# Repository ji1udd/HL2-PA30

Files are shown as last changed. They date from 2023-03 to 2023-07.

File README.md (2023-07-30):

# PA30 - 30W amplifier/filter companion board for Hermes Lite 2+ / 2

## All board, Hermes Lite 2 beta5, AK4951 companion board v3 and PA30 companion board v1, are installed in Makerfabs 40mm height enclosure.

### Exterior view
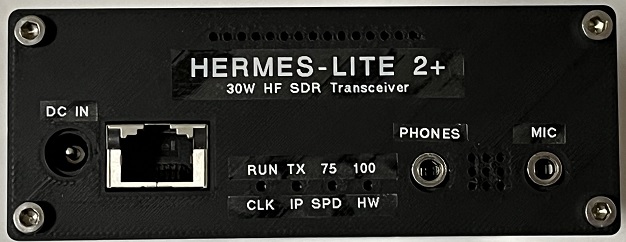
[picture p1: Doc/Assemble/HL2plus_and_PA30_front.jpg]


### Interior view (PA30 ver1 board)
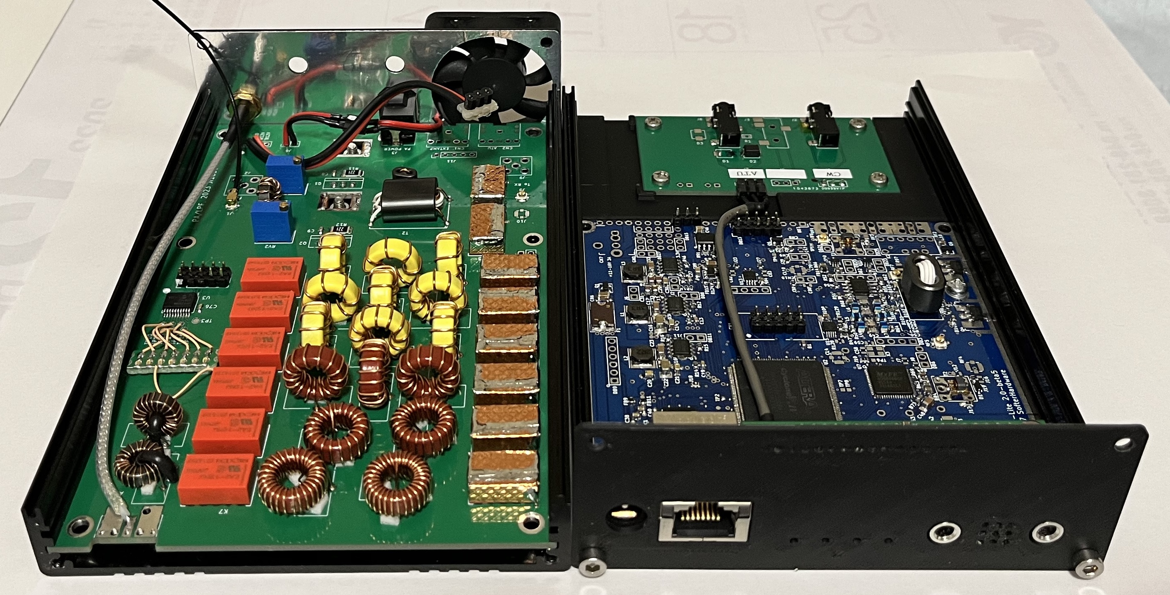
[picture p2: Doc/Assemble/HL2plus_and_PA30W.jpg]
  

### Feature
- RD15HVF1 push-pull 30W linear amplifier.
- A retired notebook AC adaptor is used to supply 19.5V to RD15HVF1.
- Tx/Rx LPF and Rx HPF ; same control as N2ADR filter
- FWD/REV sensor ; Alex type
- Tx RF feedback path for PureSignal.
- Phones and Mic Jacks are placed on the front panel, and CW key jack on the rear.

### Test result
- [_Tx Power with comparison of RD15HVF1s and RD16HHF1s_](Doc/PowerMeter/RD15_RD16_comparison_on_PA30.jpg)  
  Tx power is lower if RD16s is used instead of RD15s.
- [_Thetis FWD Power Meter_](Doc/PowerMeter/Test_FwdMeter_40M_CW.jpg)
- Spur at 30W [_160M_](Doc/Spur/Spur_160M_30W.jpg) , [_80M_](Doc/Spur/Spur_80M_30W.jpg) , [_40M_](Doc/Spur/Spur_40M_30W.jpg) , [_20M_](Doc/Spur/Spur_20M_30W.jpg) , [_15M_](Doc/Spur/Spur_15M_30W.jpg)
- PureSignal at 30W [_ON_](Doc/PureSignal/IMD_40M_30W_PS-ON.jpg), [_OFF_](Doc/PureSignal/IMD_40M_30W_PS-OFF.jpg)

### Latest design files ver2.1
There are some errata on my 1st design (v1). Schematic and pcb layout have been revised to fix them. There is no DRC error on KiCad but these are not actually build and verified.
- [_Schematic_](Schematic/PA30_v2r1_schematic.pdf)
- [_BOM_](BOM/PA30_BOM.pdf)
- [_Gerber_](Gerber/PA30_v2r1.zip)
- [_PA30-HL2 board connection_](Schematic/PA30_HL2_connection.pdf)

### PA30 Assembly
- Trans and coil  
    [_T1_](Doc/Assemble/T1_bifilar_12turns.jpg) , [_T2_](Doc/Assemble/T2_4turns_1turnx2.jpg) , [_L1_](Doc/Assemble/L1_1turn.jpg)  
    T3, T4 : UEW 0.32mm  
    LPF 160M, 80M : UEW 0.5mm  
    LPF 40M, 30/20M, 17/15M, 12/10M : UEW 0.6mm
- RD15HVF1 grounding  
    It's necessary to connect RD15HVF1 source tab to GND pattern of PCB  shortly. Otherwise amplifier will not work well. eg. lower power output... Copper tape is used. ( [_Photo_](Doc/Assemble/RD15Tab.jpg) )   
- RD15HVF1 idle current  
    Q1, Q2 idle current is set to 250mA per Tr (total 500mA).

### HL2 modification
- Reduce HL2 RF output power to avoid over drive ; 37dBm -> 26dBm  
    R55 : Replace 120ohms with 750ohms. Otherwise Q1 and Q2 will be broken.

- uFL Tx output  
    RF7 and B55 : Install  
    B98 : Uninstall

- uFL Rx input  
    RF5 : Install  
    B81 : Uninstall

- CW KEY jack  
    Jack(CN4) and jumper(J13) : Uninstall to get clearance to jacks on CBV3.  ( [_Photo_](Doc/Assemble/CN4_1.jpg) )   
    Instead of the uninstalled jack CN4, 3.5mm jack is placed on rear panel. ( [_Photo_](Doc/Assemble/CN4_2.jpg) )  
    Wire is used to connect between PCB and the jack.

- Pin Header  
    Low profile pin header and socket are used.   ( [_Photo_](Doc/Assemble/LowProfilePinHeader.jpg) )  
    CN1, DB1, DB12, DB13, DB7 Pin12-14 ( [_Photo_](Doc/Assemble/HL2_PinHeader.jpg) )

### AK4951 CBV3 modification  
- [_Stacked boards Photo_](Doc/Assemble/stacked_boards.jpg)
- Mic/PTT jack and Phone jack  
    They are relocated on the opposite PCB side. ( [_Photo_](Doc/Assemble/CBV3_1.jpg) )  
    Therefore the signals assigned to Tip and Ring are swapped.   
    C3 10uF on CBV3 is removed to mount Mic/PTT jack. There is no side effect in my case.

- Pin Header  
    Low profile pin header and socket are used.   ( [_Photo_](Doc/Assemble/LowProfilePinHeader.jpg) )  

- Jack Spacer (option)  
    The B2B Pin Header/Socket height and jack height are different.  
    Therefore 3D printed spacer (t = 0.7mm) is used between jack and PCB to fix tightly. ( [_Photo_](Doc/Assemble/CBV3_2.jpg) )  

- CVB3 Support part (option)  
    The 3D printed support part that fixes CBV3 and HL2 tightly, is used. ( [_Photo_](Doc/Assemble/CBV3_3.jpg) ) 

### Cooling fan
- 40mm square. ( [_Photo_](Doc/Assemble/fan.jpg) )

### Shield (option)  
- This is risk hedge.  I have not verified if it's essencial or not.
- Relay shield (copper tape is used) intend to isolate LPF input and output, and to isolate Tx  and Rx. ( [_Photo_](Doc/Assemble/relay_shield.jpg) )
- 3D printed shield between HL2 and PA30  
    Aluminum tape is used. ( [_Photo_](Doc/Assemble/B2B_shield.jpg) )

### 3D print files
- [_Jack spacer_](3D_Print/jack_3r5_spacer%20v3.stl)
- [_CBV3 support_](3D_Print/HL2_cbv3_support%20v1.stl)
- [_B2B Shield_](3D_Print/RF_shield%20v32.stl)
- [_Front Panel_](3D_Print/FrontPanel%20v1.stl)
- [_Rear Panel_](3D_Print/HL2_RearPanel2%20v4.stl)
- [_HL2 spacer instead of N2ADR board_](3D_Print/HL2_spacer3%20v5.stl)

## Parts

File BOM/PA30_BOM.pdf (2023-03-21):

Designator | Qty. | Value/Description | Package | Manufacture | Manufacturer P/N | Supplier | Supplier P/N
C1, C2 | 2 | CAP CER 1uF 25V X5R | 0603(1608) | Murata | GRM188R71E105KA12
C3, C6, C7, C11, C12, C15, C16, C19, C20, C21, C22, C23, C24, C25, C26, C27, C28, C29, C30, C69, C70, C71, C72, C73, C74, C75, C76, C77, C81, C82, C83, C84, C85, C86, C87, C88, C89, C90, C91, C92, | 40 | CAP CER 100nF 50V X7R | 0603(1608) | Samsung | CL10B104KB8NNNL | Digi-Key | 1276-CL10B104KB8NNNLCT-ND
C4, C5, C8, C9 | 4 | CAP CER 100nF 100V X7R 10% | 0603(1608) | Samsung | CL10B104KC8NNNC | Mouser | 187-CL10B104KC8NNNC
C10, C44, | 2 | CAP CER 270pF 630V C0G 5% | 1206(3216) | TDK | C3216C0G2J271J060AA | Mouser | 810-C3216C0G2J271J
C13, C14, C17, C18, | 4 | CAP CER 22uF 25V X5R | 0805(2012) | Murata | GRM21BR61E226ME44L | Mouser | 81-GRM21BR61E226ME4L
C31, C65, | 2 | CAP CER 330pF 630V C0G 5% | 1206(3216) | Yageo | CC1206JKNPOZBN331 | Mouser | 603-CC206JKNPOZBN331
C32, C46, C58, | 3 | CAP CER 120pF 630V C0G 5% | 1206(3216) | Walsin | 1206N121J631CT | Mouser | 791-1206N121J631CT
C33, C94, | 2 | CAP CER 47pF 500V C0G 5% | 1206(3216) | Walsin | 1206N470J501CT | Mouser | 791-1206N470J501CT
C34, C49, C63, | 3 | CAP CER 39pF 500V C0G 5% | 1206(3216) | Yageo | CC1206JRNPOBBN390 | Mouser | 603-CC126JRNPOBBN390
C35, | 1 | CAP CER 1500pF 630V C0G 5% | 1206(3216) | TDK | C3216C0G2J152J115AA | Mouser | 810-C3216C0G2J152J
C36, | 1 | CAP CER 560pF 630V C0G 5% | 1206(3216) | TDK | C3216C0G2J561J085AA | Mouser | 810-C3216C0G2J561J
C37, | 1 | DNI
C38, C68, | 2 | CAP CER 27pF 500V C0G 5% | 1206(3216) | Yageo | CC1206JRNPOBBN270 | Mouser | 603-CC126JRNPOBBN270
C39, | 1 | CAP CER 15pF 500V C0G 5% | 1206(3216) | Yageo | CC1206JRNPOBBN150 | Mouser | 603-CC126JRNPOBBN150
C40, | 1 | CAP CER 8.2pF 500V C0G ±0.5pF | 1206(3216) | Walsin | 1206N8R2D501CT | Mouser | 791-1206N8R2D501CT
C41, C57, | 2 | CAP CER 150pF 630V C0G 5% | 1206(3216) | Yageo | CC1206JKNPOZBN151 | Mouser | 603-CC126JKNPOZBN151
C42, C62, | 2 | CAP CER 82pF 500V C0G 5% | 1206(3216) | Murata | GRM31A5C2H820JW01D | Mouser | 81-GRM31A5C2H820JW1D
C43, C55, | 2 | CAP CER 680pF 500V C0G 5% | 1206(3216) | Yageo | CC1206JRNPOBBN681 | Mouser | 603-C1206JRNPOBBN681
C45, | 1 | CAP CER 160pF 630V C0G 1% | 1206(3216) | KEMET | C1206C161JBGACTU | Mouser | 80-C1206C161JBG
C47, | 1 | CAP CER 3000pF 500V C0G 5% | 1206(3216) | KEMET | C1206C302JCGACTU | Mouser | 80-C1206C302JCGACTU
C48, C59, | 2 | CAP CER 1200pF 630V C0G 5% | 1206(3216) | TDK | C3216C0G2J122J085AA | Mouser | 810-C3216C0G2J122J
C50, C61, | 2 | CAP CER 100pF 630V CH 5% | 1206(3216) | TDK | C3216CH2J101J060AA | Mouser | 810-C3216CH2J101J06A
C51, | 1 | CAP CER 43pF 630V C0G 5% | 1206(3216) | KEMET | C1206C430JBGACTU | Mouser | 80-C1206C430JBG
C52, C64, C95, | 3 | CAP CER 33pF 500V C0G 5% | 1206(3216) | Yageo | CC1206JRNPOBBN330 | Mouser | 603-CC126JRNPOBBN330
C53, | 1 | CAP CER 510pF 630V 5% | 1206(3216) | KEMET | C1206C511JBGACTU | Mouser | 80-C1206C511JBG
C54, C56, | 2 | CAP CER 220pF 630V 5% | 1206(3216) | TDK | C3216C0G2J221J060AA | Mouser | 810-C3216C0G2J221J
C60, | 1 | CAP CER 470pF 500V C0G 5% | 1206(3216) | Yageo | CC1206JRNPOBBN471 | Mouser | 603-CC206JRNPOBBN471
C66, | 1 | CAP CER 68pF 630V C0G 5% | 1206(3216) | Walsin | 1206N680J631CT | Mouser | 791-1206N680J631CT
C67, | 1 | CAP CER 22pF 500V C0G 5% | 1206(3216) | Yageo | CC1206JRNPOBBN220 | Mouser | 603-CC126JRNPOBBN220
C78, C80, | 2 | CAP CER 1500pF 100V C0G 5% | 0805(2012) | TDK | CGA4C2C0G2A152J060AA | Mouser | 810-CGA4C2C0G2A152J
C79, | 1 | CAP CER 680pF 100V C0G 5% | 0805(2012) | Yageo | CC0805JRNPO0BN681 | Mouser | 603-CC805JRNPO0BN681
C93, | 1 | CAP CER 10pF 500V C0G 5% | 1206(3216) | Yageo | CC1206JRNPOBBN100 | Mouser | 603-CC126JRNPOBBN100
CN1, CN2 | 1 | 3.5mm Jack 3-contact | - | CUI | SJ1-3525N | Mouser | 490-SJ1-3525N
D1, D2, D3, D4, | 4 | Schottky Diode | SOD-323 | Diodes Nexperia | 1N5711WS RB751V40,115 | Mouser | 771-RB751V40,115
D5, | 1 | Diode 1000V 1A | DO-214AC(SMA) | Diodes | S1M-13-F | Mouser | 621-S1M-F
D6, | 1 | TVS Diode | DO-214AC(SMA) | Littelfuse | SMBJ6.0CA | Mouser | 576-SMBJ6.0CA
D7, D8, D9, D10, D11, D12, D13, | 7 | LED | 0603(1608) | Lite-On | LTST-C190GKT | Mouser | 859-LTST-C190GKT
F1, | 1 | Resettable Fuse 3A | - | Bourns | MF-LSMF300/24X-2 | Mouser | 652-MF-LSMF300/24X-2
FB1, | 1 | FB 100MHz 1A.25% | 0603 (1608) | TDK | MPZ1608S601ATA00 | Mouser | 810-MPZ1608S601ATA00
J1, J8, J10, J13, | 4 | uFL Male | - | - | - | Aliexpress
J2, J9, | 2 | SMA | - | - | - | - | -
J3, | 1 | DC POWER JACK EIAJ-5 | - | CUI | PJ-025 | Mouser | 490-PJ-025

J4, | 1 | SMA/BNC | - | - | - | - | -
J5, | 1 | Low Profile Pin header 2.54mm 5 x 2 pin | - | - | - | - | -
J6, J12, | 1 | Low Profile Pin header 2.54mm 2 x 1 pin | - | - | - | - | -
J7, | 1 | Low Profile Pin header 2.54mm 3 x 1 pin | - | - | - | - | -
J11, | 1 | Pin header 2.54mm 5 x 1 pin | - | - | - | - | -
K1, K2, K3, K4, K5, K6, K7, K8, K9, K10, K11, K12, K13, K14, | 14 | EA2-12 | - | KEMET | EA2-12NU | DigiKey | 399-17332-5-ND
L1, | 1 | multi-aperture core | - | Amidon | BN43-2402 | Kits and Parts | BN43-2402
L2, L6, L7, L8, L12, L13, L14, | 7 | powdered iron toroid | - | Amidon | T50-2 | Kits and Parts | T50-2
L3, L4, L5, L9, L10, L11, L15, L16, L17, | 9 | powdered iron toroid | - | Amidon | T50-6 | Kits and Parts | T50-6
L18, L19, | 2 | IND 1.8uH | 0805(2012) | Taiyo Yuden | LBM2016T1R8J | Mouser Digi-Key | 963-LBM2016T1R8J 587-3092-1-ND
Q1, Q2, | 2 | RF Power MOS FET | TO-220 | Mitsubishi | RD15HVF1 | RS | 690-0127
Q3, | 1 | Pch FET | SOIC-8 | Diodes | 621-DMP3036SSS-13 | Mouser | 621-DMP3036SSS-13
Q4, | 1 | Pch FET | SOT23_3 | Infineon | IRLML6402TRPBF | Digi-Key | IRLML6402PBFCT-ND
Q5, | 1 | Nch FET | SOT-23 | ONsemi | 2N7002ET1G | Mouser | 863-2N7002ET1G
R1, | 1 | RES 560 ohm | 0603(1608)
R2, R6, | 2 | DNI | 0805(2012) | - | - | - | -
R3, | 1 | RES 0 ohm | 0805(2012)
R4, | 1 | RES 4.7k ohm | 0603(1608)
R5, | 1 | RES 2.2k ohm | 0603(1608)
R7, R8, R19, R21, R29, | 5 | RES 1k ohm | 0603(1608)
R9, R10, | 2 | RES 10 ohm | 0603(1608)
R11, R12, | 2 | RES 220 ohm 0.75W 1% | 2010(5025) | Yageo | RC2010JK-07220RL | Mouser | 603-RC2010JK-07220RL
R13, R30, | 2 | RES 56 ohm | 0603(1608)
R14, R16, | 2 | RES 100k ohm | 0603(1608)
R15, | 1 | RES 49.9 ohm 0.1W 1% | 0603(1608) | Bourns | CR0603-FX-49R9ELF | Mouser | 652-CR0603FX-49R9ELF
R17, R18, | 2 | RES 220k | 0603(1608)
R20, R22, | 2 | RES 1.8k | 0603(1608)
R23, | 1 | RES 100 ohm | 0603(1608)
R24, R28, | 2 | RES 10k ohm | 0603(1608)
R25, R27, | 2 | RES 110 ohm | 0603(1608)
R26, | 1 | RES 51.1 ohm | 0603(1608)
R31, | 1 | RES 430 ohm | 0603(1608)
R32, R33, R34, R35, R36, R37, R38, | 7 | RES 1.5k ohm | 0603(1608)
RV1, RV2, | 2 | RES Trimmer 10k ohm | - | Bourns | 3296W-1-103LF | Mouser | 652-3296W-1-103LF
T1, T3, T4, | 3 | ferrite toroid | - | Amidon | FT37-43 | Kits and Parts | FT37-43
T2, | 1 | multi-aperture core | - | Amidon | BN43-202 | Kits and Parts | BN43-202
U1, | 1 | Shunt Regulator | SOT89-3 | Toshiba | TA76431F | Chip One Stop | C1S751200341120
U2, | 1 | OPAMP | SOIC-8 | TI | LMC6482IMX/NOPB | Digi-Key | LMC6482IMXCT-ND
U3, | 1 | I/O Expander | SSOP-20 | Microchip | MCP23008-E/SS | Digi-Key | MCP23008T-E/SS
U4, | 1 | Low Side Driver | TSSOP-16 | Diodes TI TI | ULN2003V12T16-13 TPL7407LPWR TPL7407LAPWR | Mouser | 621-ULN2003V12T16-13 595-TPL7407LPWR 595-TPL7407LAPWR
HL2 RF7 - PA30 J1 | 1 | uFL/IPEX-1 cable Female-Female 10cm | Aliexpress
HL2 RF5 - PA30 J8 PA30 J10 - PA30 J13 | 2 | uFL/IPEX-1 cable Female-Female 15cm | Aliexpress

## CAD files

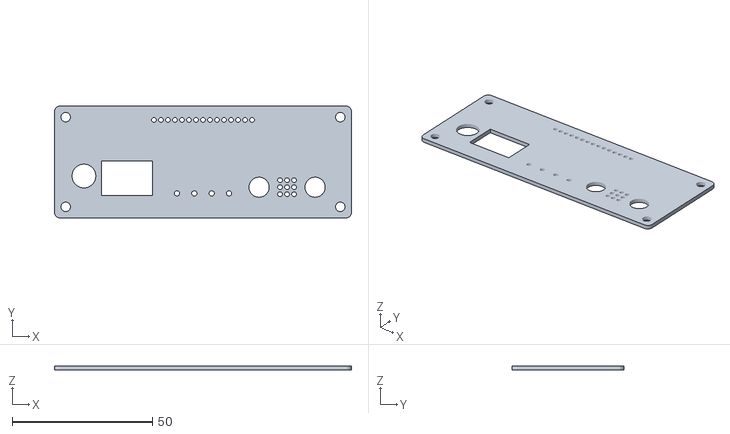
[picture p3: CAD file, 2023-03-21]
3D_Print/FrontPanel v1.stl
106.0 x 40.0 x 1.50

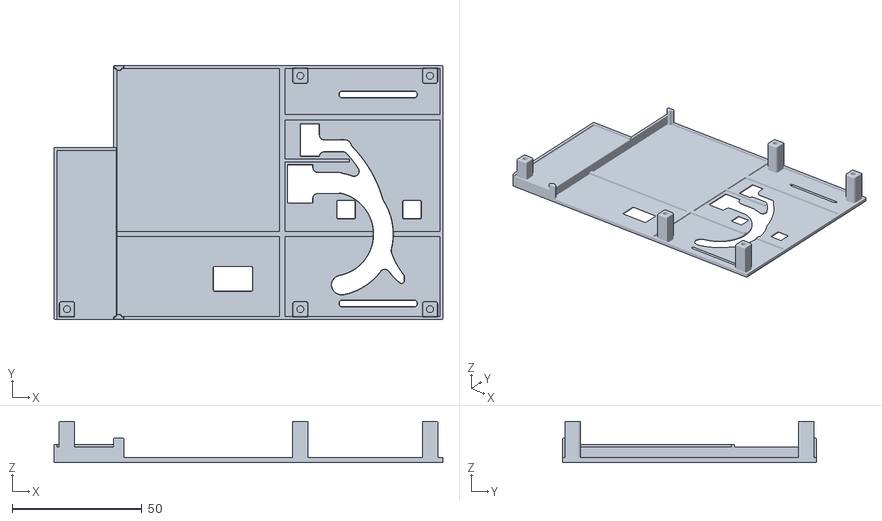
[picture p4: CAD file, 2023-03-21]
3D_Print/RF_shield v32.stl
150.0 x 98.0 x 16.0

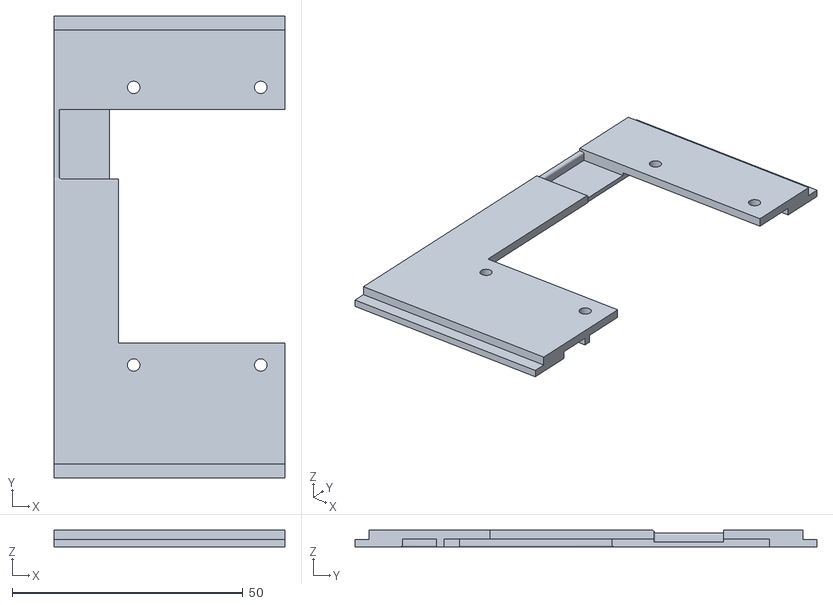
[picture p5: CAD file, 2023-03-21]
3D_Print/HL2_spacer3 v5.stl
50.0 x 100.0 x 3.60

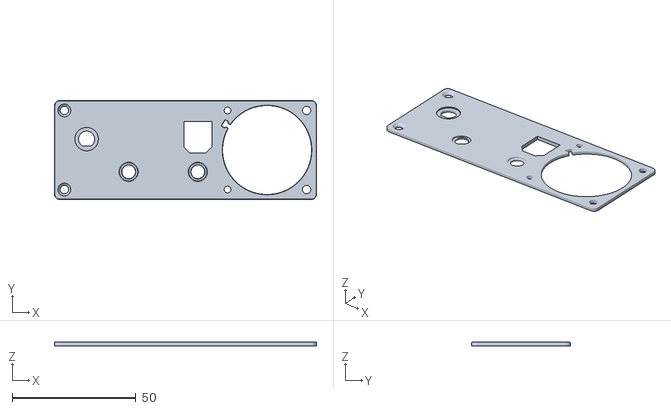
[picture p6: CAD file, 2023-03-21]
3D_Print/HL2_RearPanel2 v4.stl
106.0 x 40.0 x 1.50

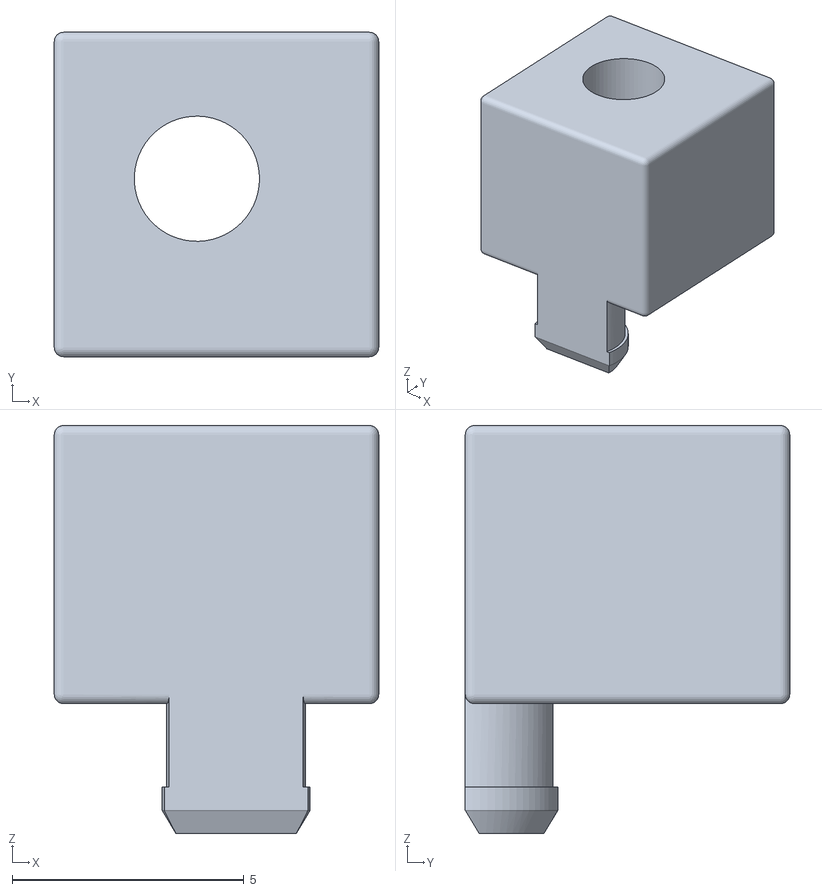
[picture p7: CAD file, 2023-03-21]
3D_Print/HL2_cbv3_support v1.stl
7.00 x 7.00 x 8.80

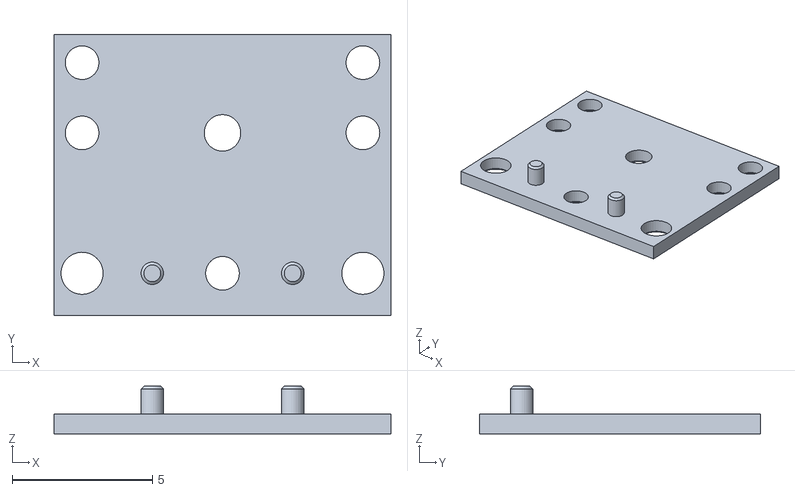
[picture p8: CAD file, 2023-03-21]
3D_Print/jack_3r5_spacer v3.stl
12.0 x 10.0 x 1.70

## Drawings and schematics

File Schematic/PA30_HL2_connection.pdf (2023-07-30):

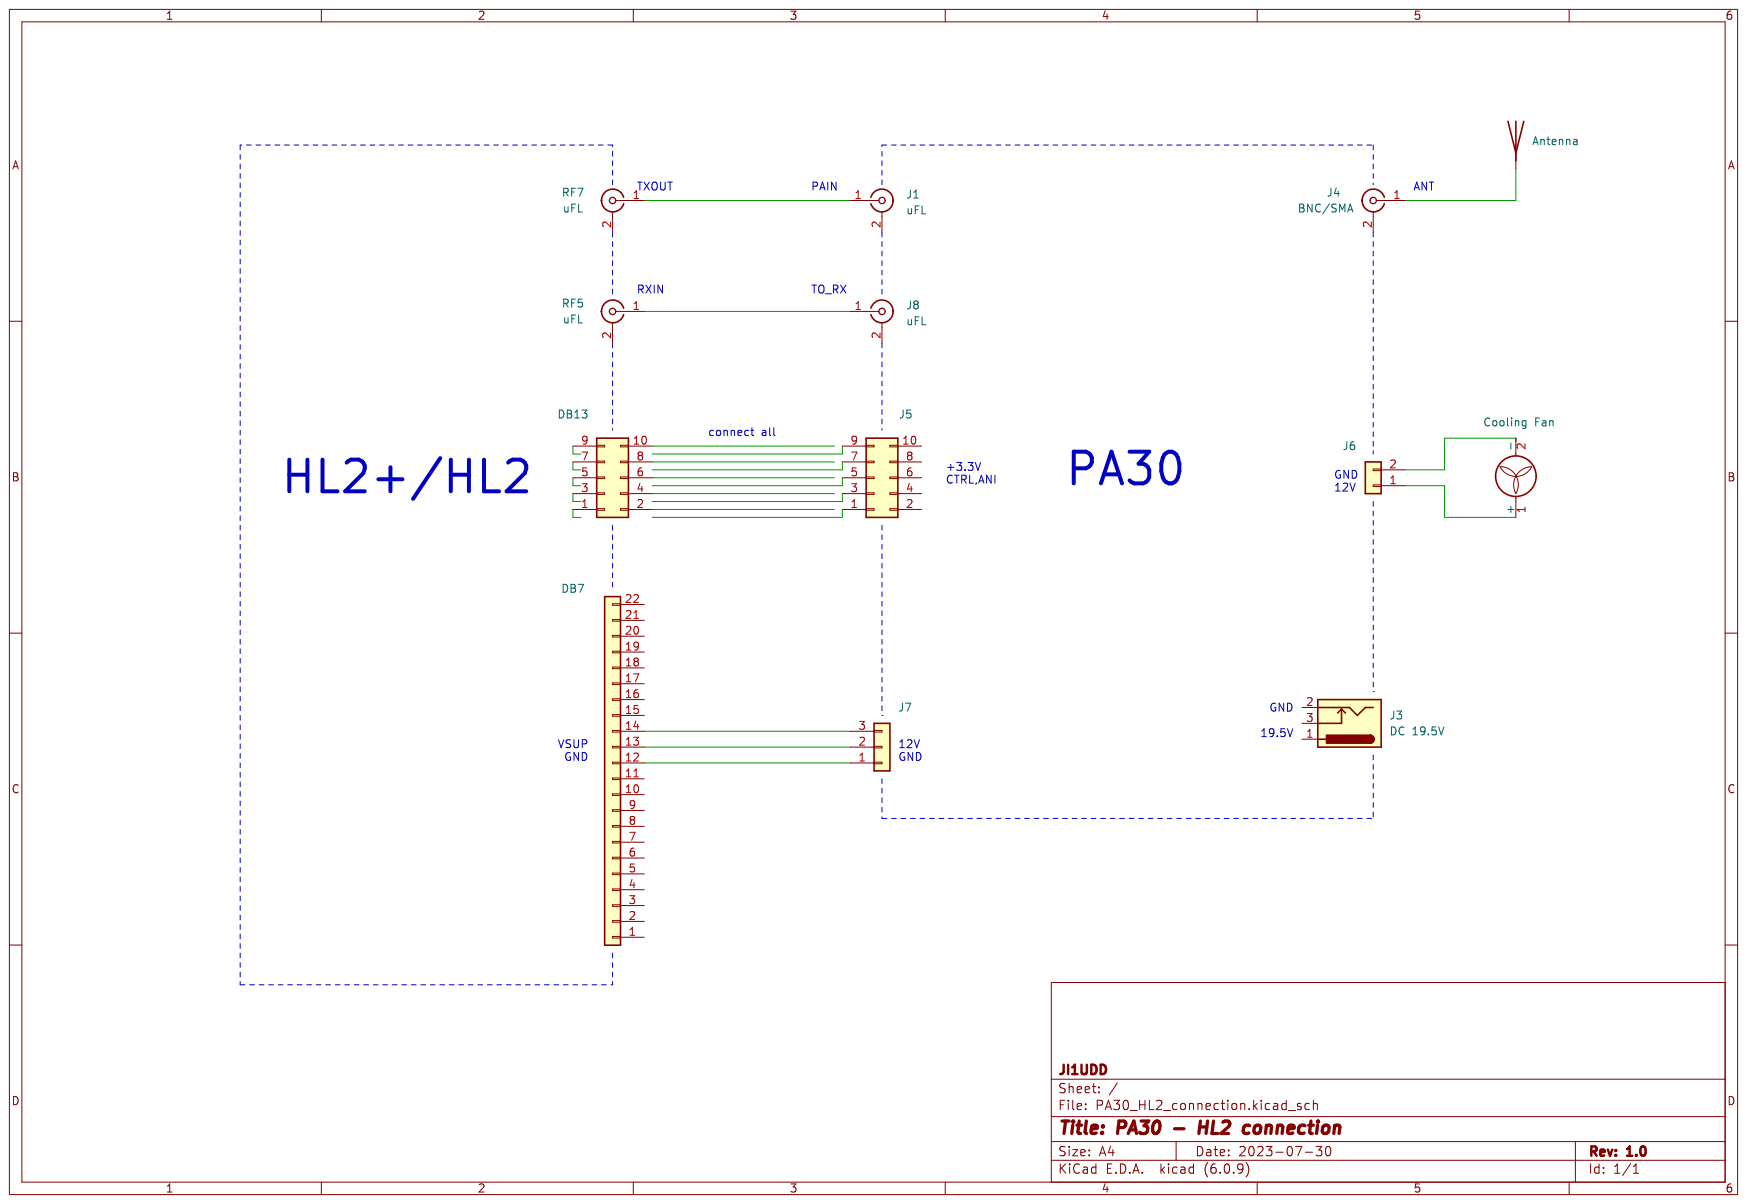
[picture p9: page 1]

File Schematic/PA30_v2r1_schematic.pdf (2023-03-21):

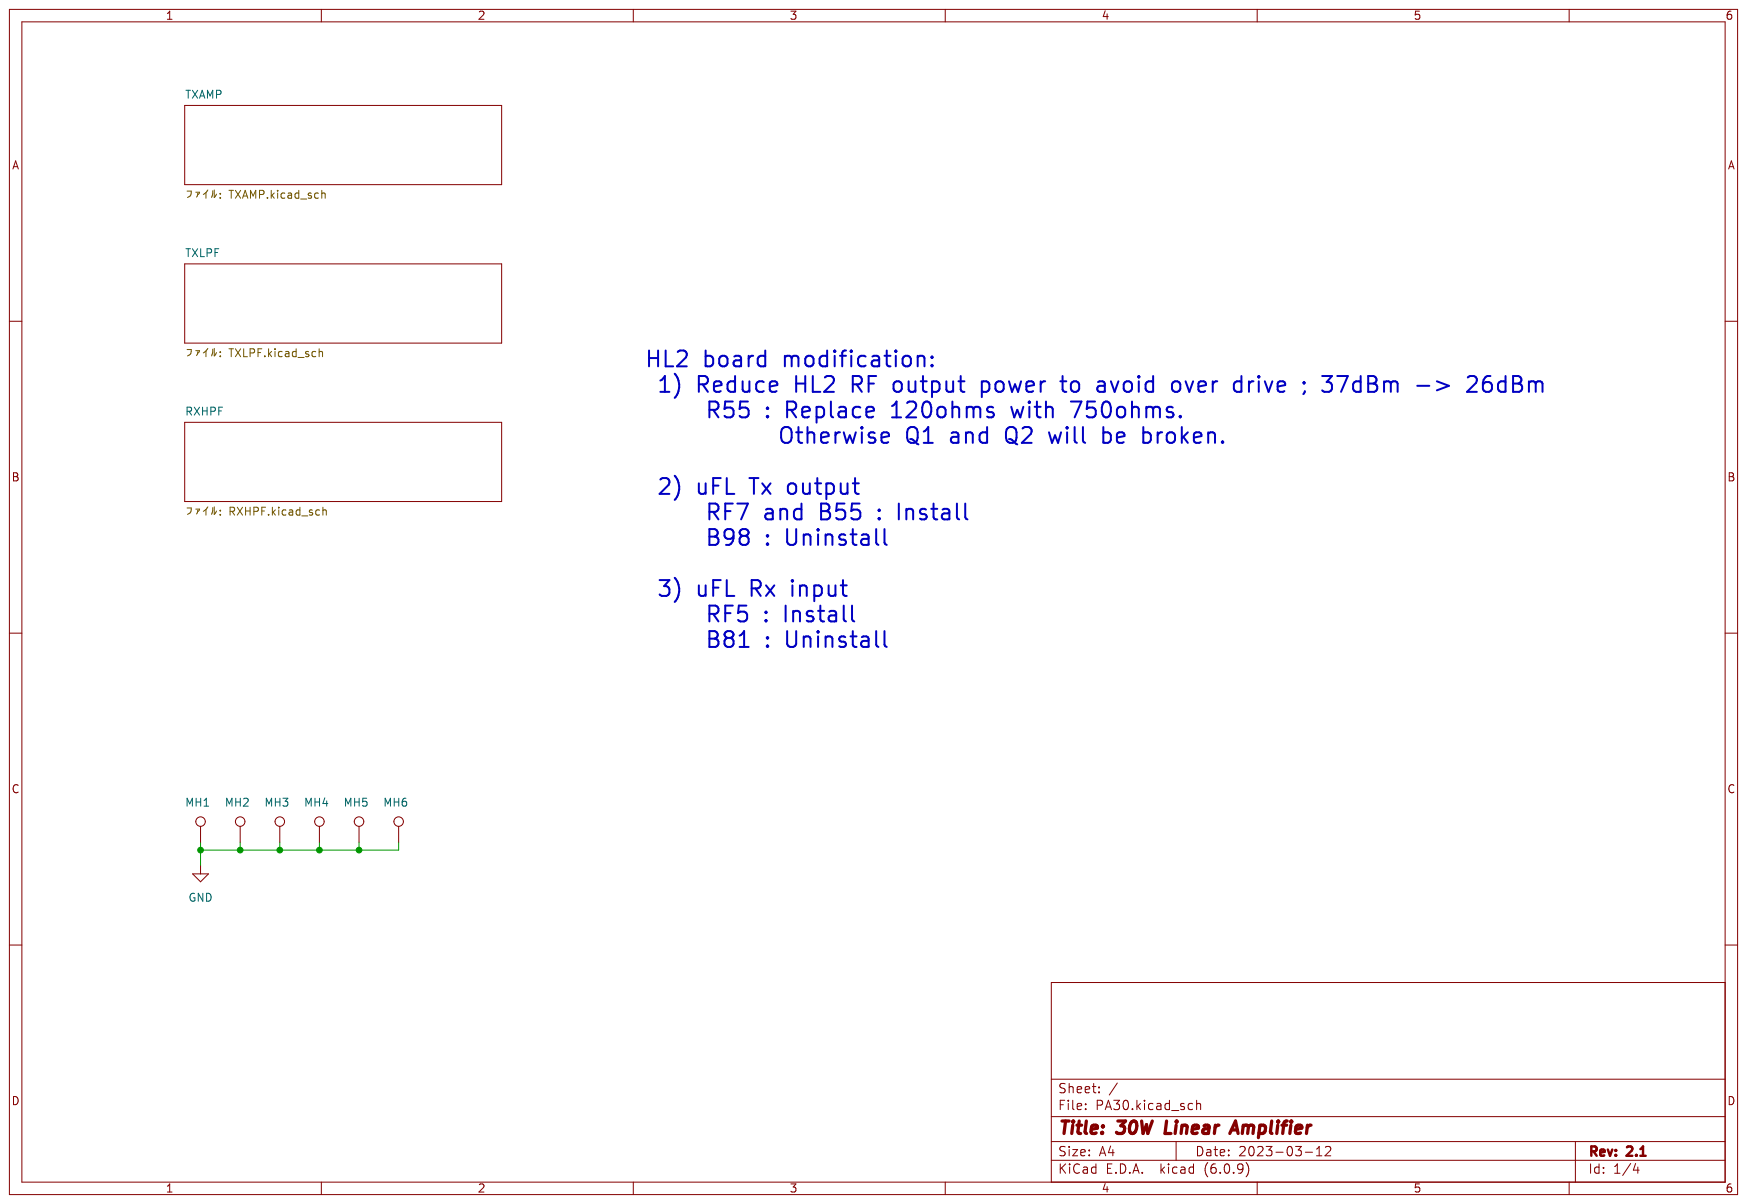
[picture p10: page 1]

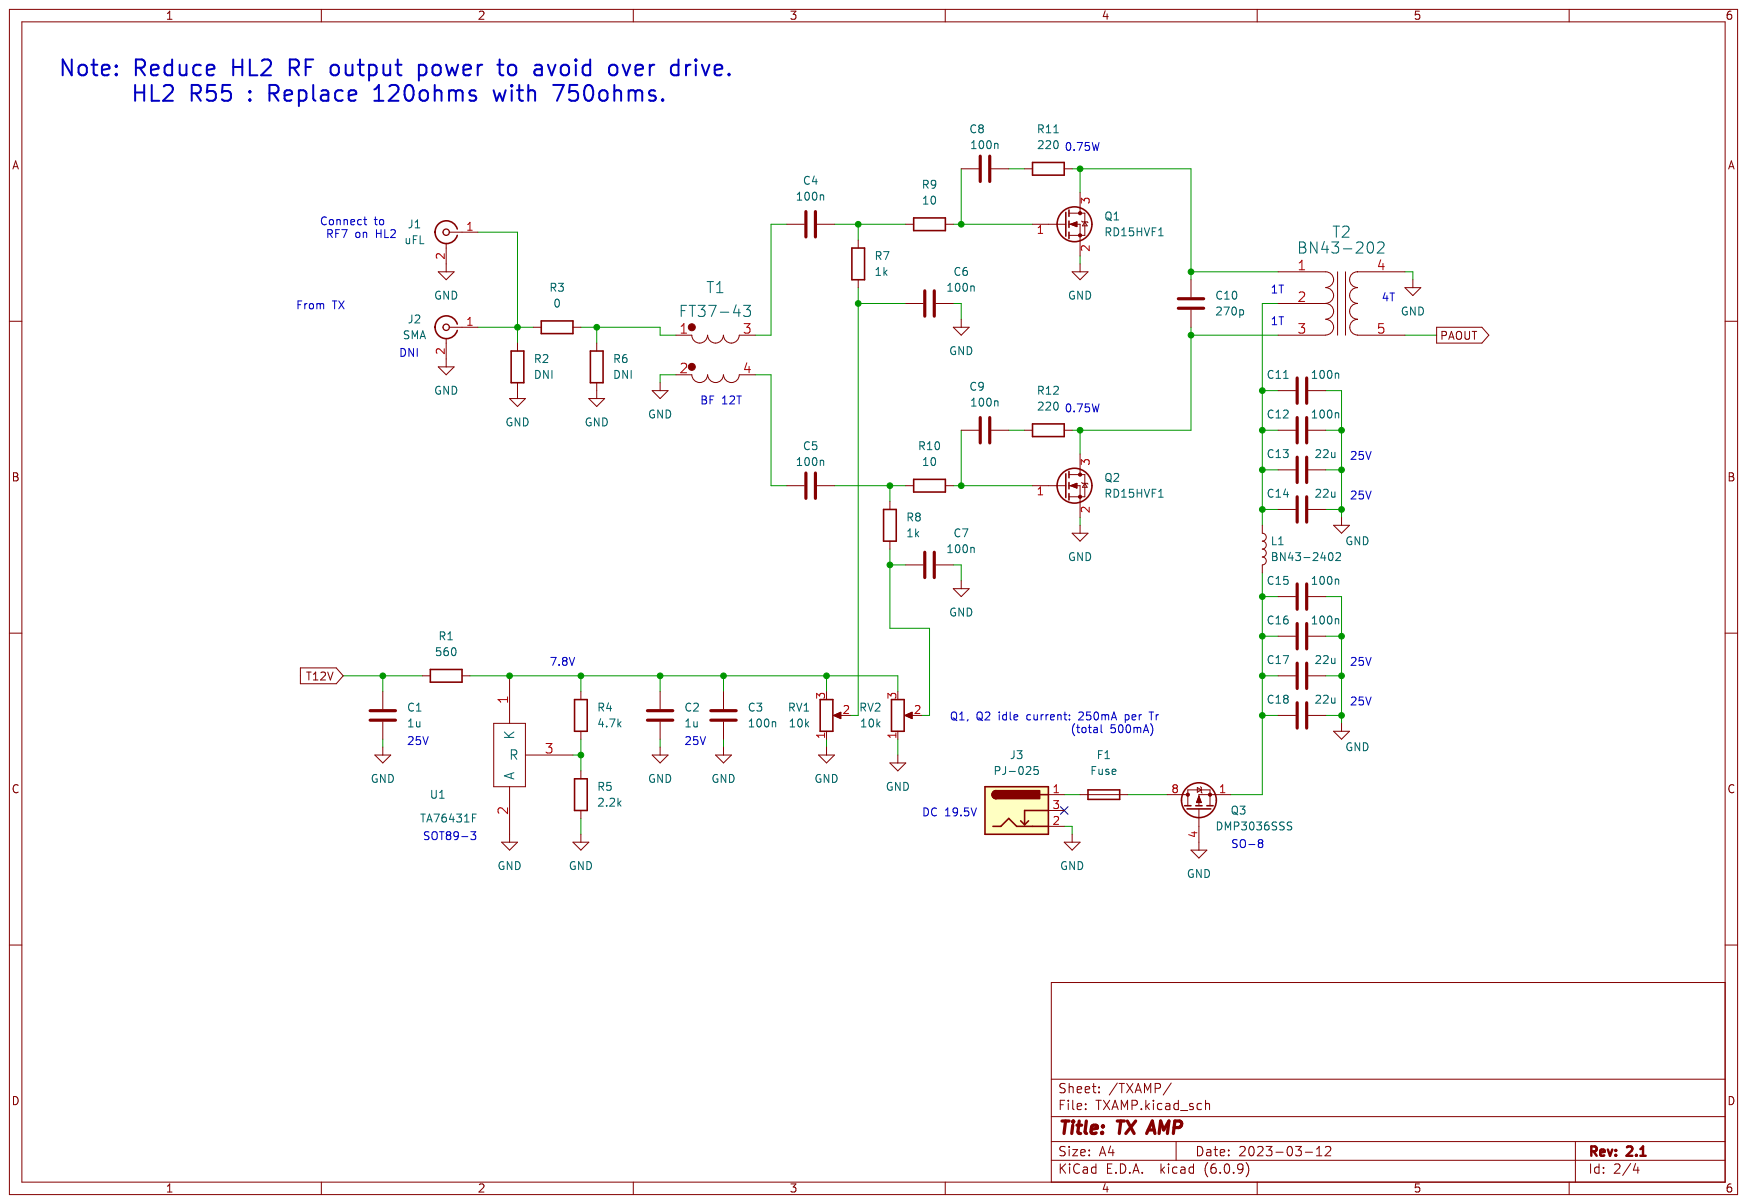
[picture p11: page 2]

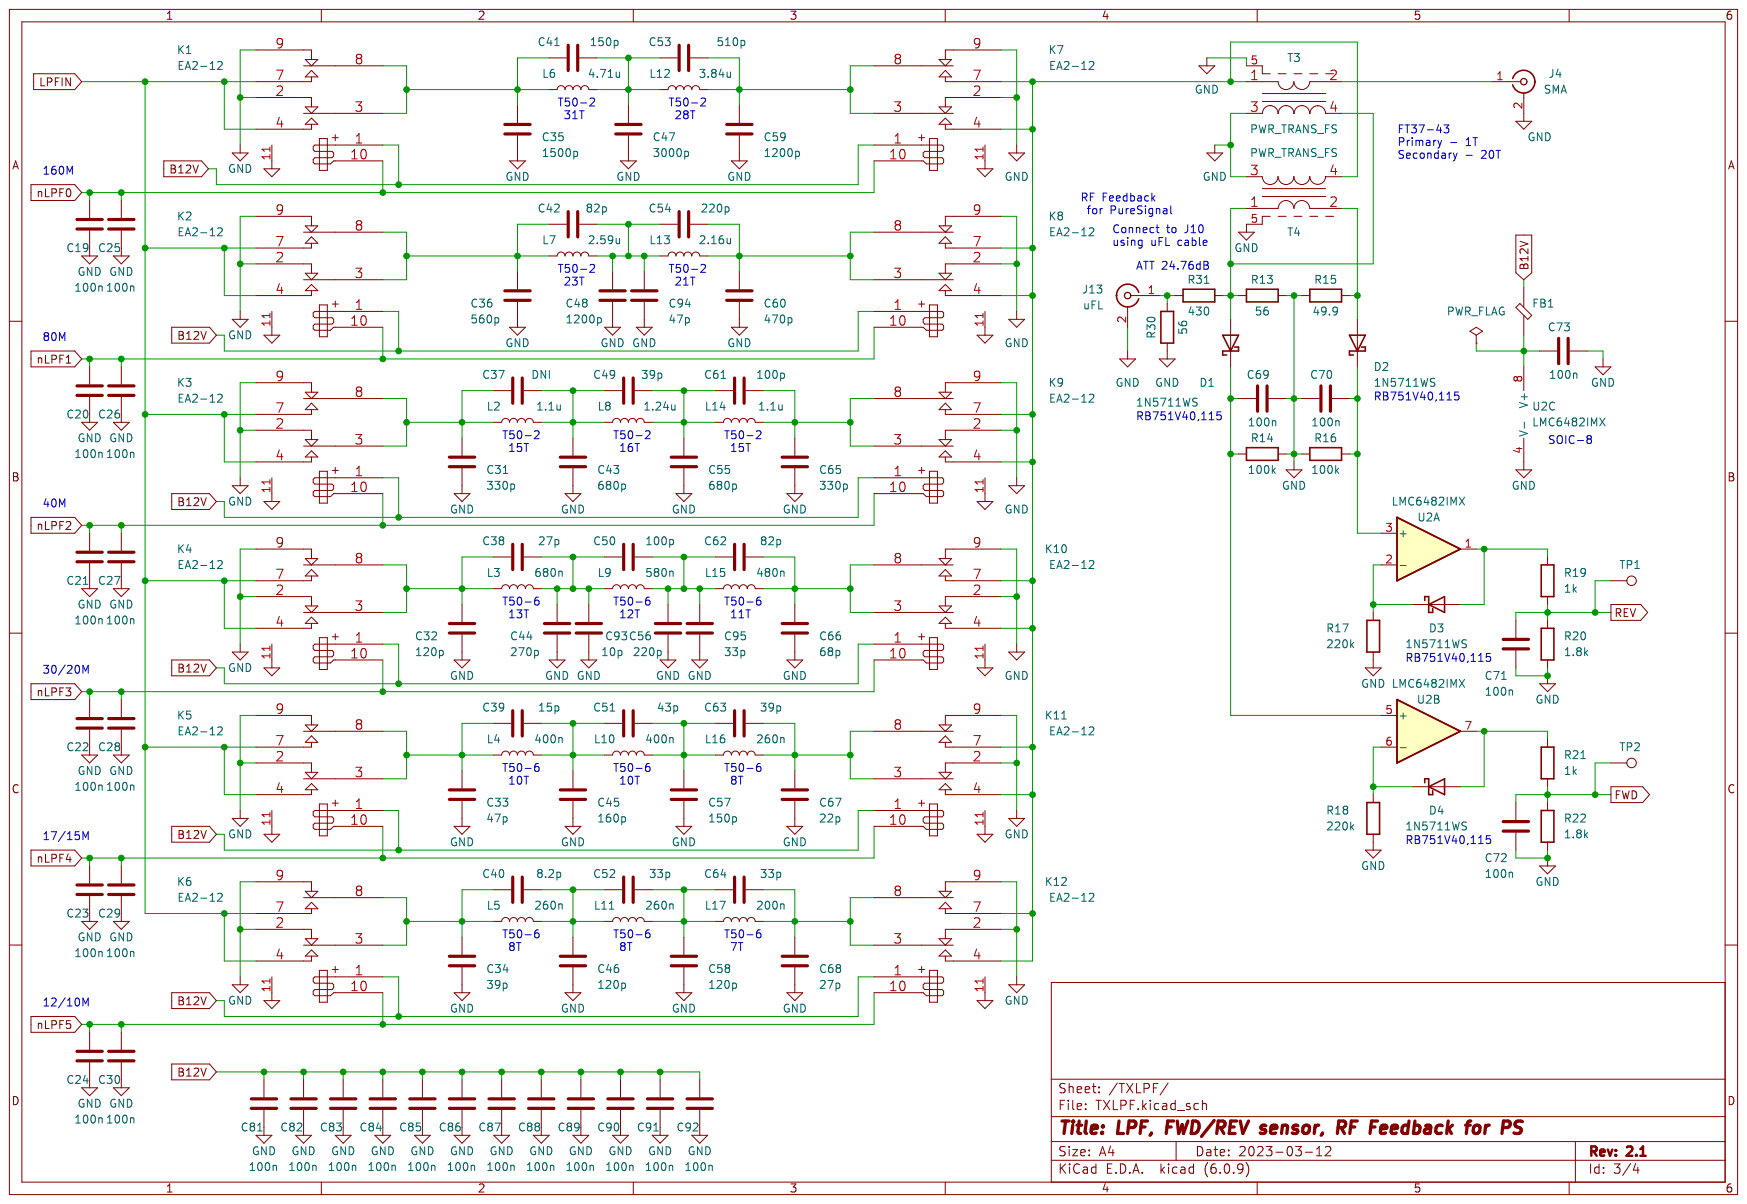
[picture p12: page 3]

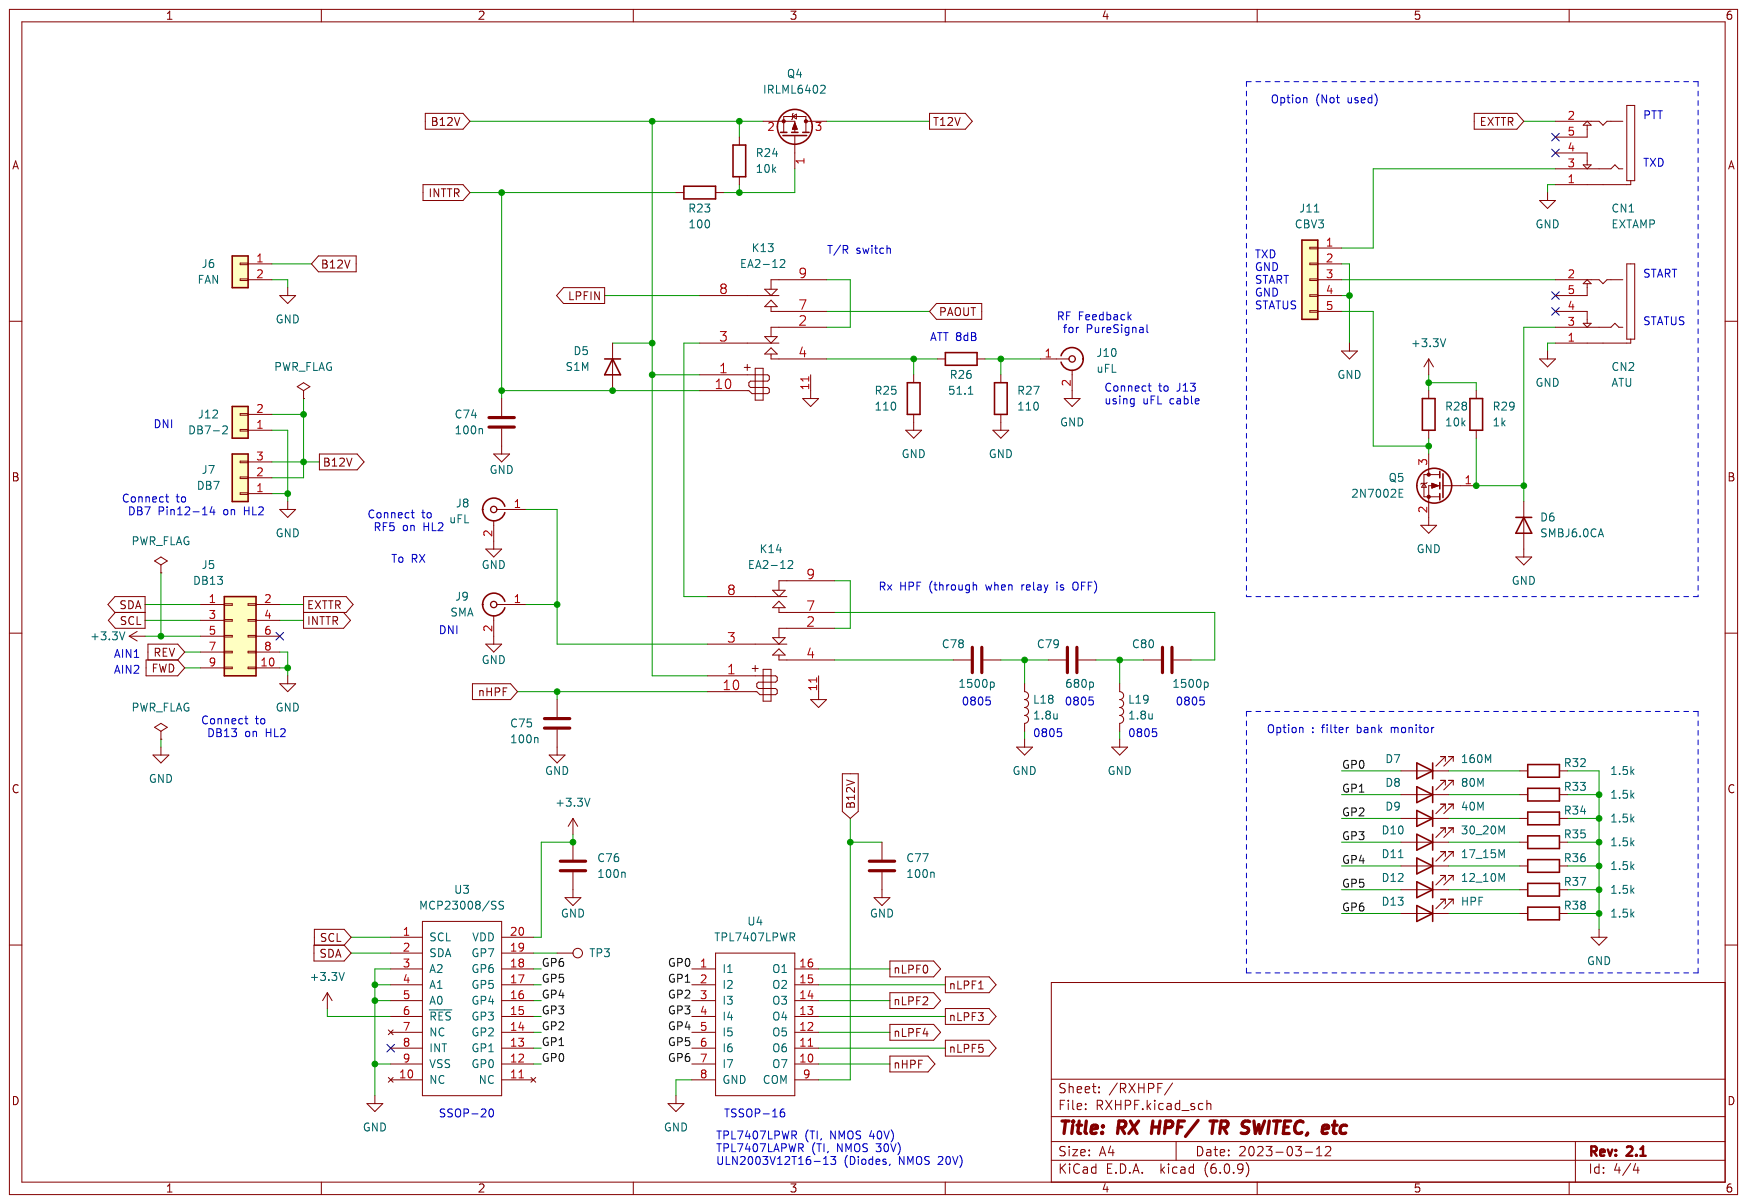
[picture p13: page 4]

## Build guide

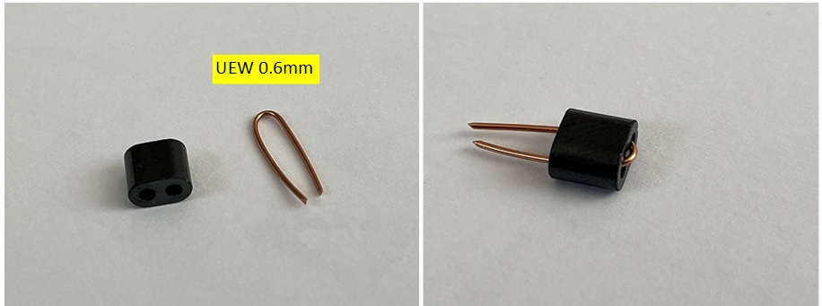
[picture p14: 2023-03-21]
Doc/Assemble/L1_1turn.jpg

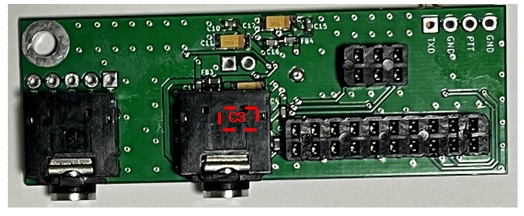
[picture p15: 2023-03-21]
Doc/Assemble/CBV3_1.jpg

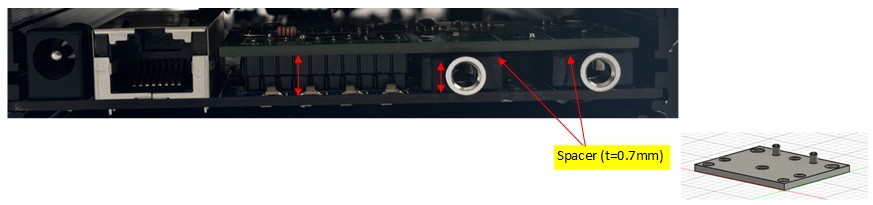
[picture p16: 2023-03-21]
Doc/Assemble/CBV3_2.jpg

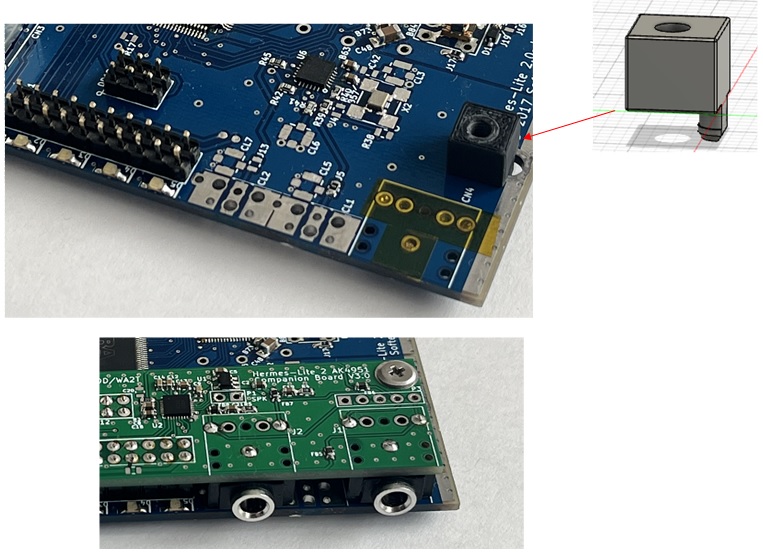
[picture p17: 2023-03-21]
Doc/Assemble/CBV3_3.jpg

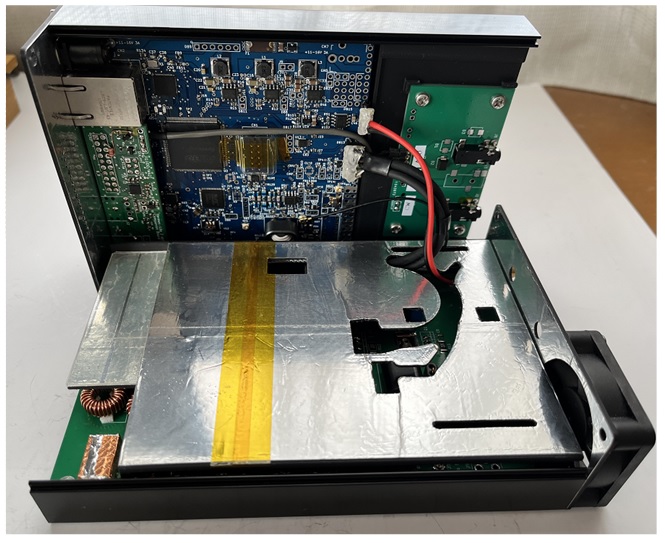
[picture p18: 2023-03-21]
Doc/Assemble/B2B_shield.jpg

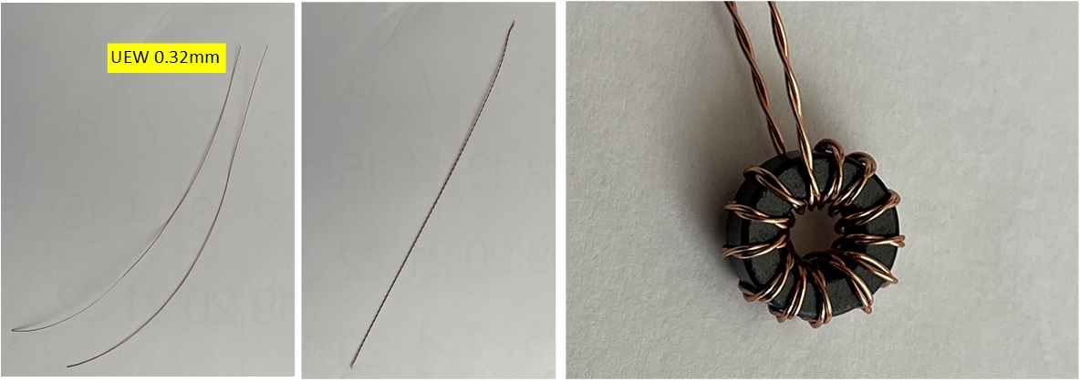
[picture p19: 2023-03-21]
Doc/Assemble/T1_bifilar_12turns.jpg

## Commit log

2023-03-21 1st release
    [FrontPanel v1.stl, HL2_RearPanel2 v4.stl, HL2_cbv3_support v1.stl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]
2023-03-21 updated T1, T2, L1 photo
    added wire information
2023-03-21 updated README.md
    added LPF, FR trans wire information
2023-03-22 update Test result
    Added Tx Power vs freq.
2023-07-30 Added PA30 - HL2 board connection schematic
